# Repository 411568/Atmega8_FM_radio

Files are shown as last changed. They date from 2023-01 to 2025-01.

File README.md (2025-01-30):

<p align="center">Atmega8_FM_radio</p>

<h2>🧐 Features</h2>

This project is a revision of one of my old designs, created a long long time ago when atmel atmega chips where still dirty cheap.

It contains two seperate boards: 
 - main_radio_board - this one contains an Atmega8 microcontroller, TEA5767 FM radio module, PAM8302 amplifier module and power connector. 
 - display_and_controls_board - this one is specificly designed to fit in an old Unitra radio case, it has LEDs used as radio frequency indicators, rotary encoder for changing the frequency, potentiometer for volume and some additional buttons.

<h2>📱 Electronics design</h2>

My FM radio is based on the TEA7567 module, that is connected to an Atmega8A-PU microconotroller via I2C. Then it's output goes to the connector, then on the main panel passes through a logarithmic potentiometer for volume control 
and comes back to the PAM8302 D-class amplifier module. I chose it because it works well with my speaker, which is the one used in the original Unitra radio (it is probably over 40 years old and still works very well).

The schematic and PCB were both designed using KiCAD 6.0

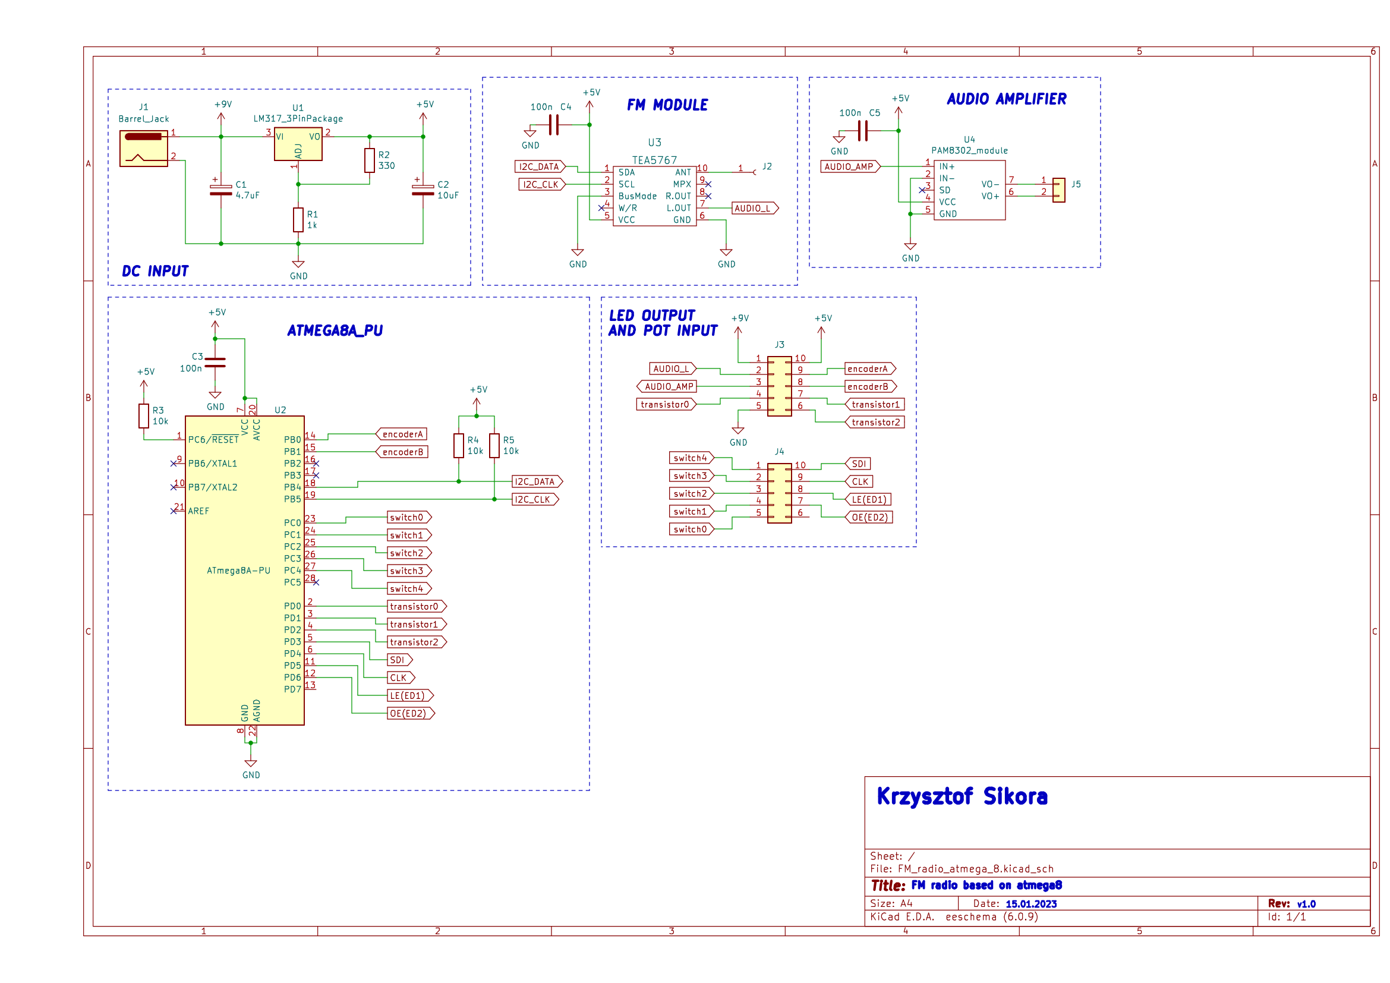
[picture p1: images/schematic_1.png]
schematic kicad


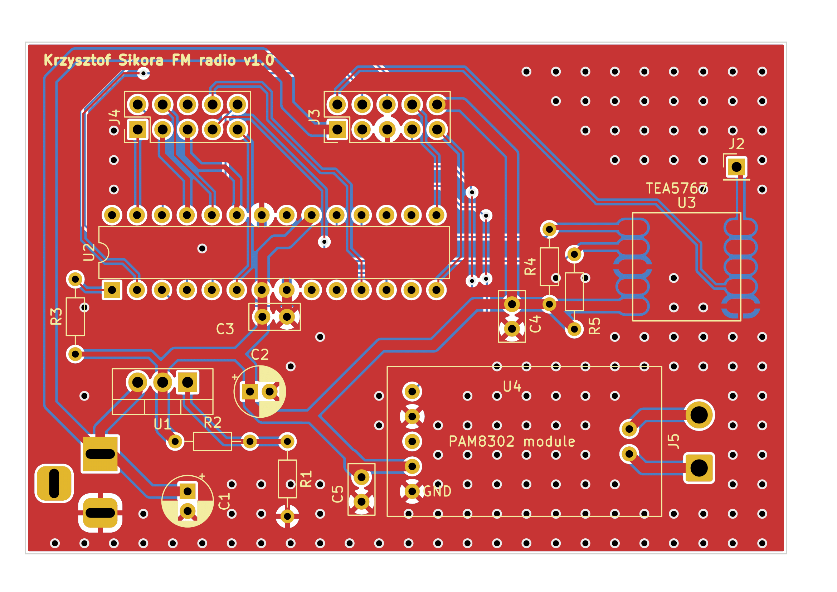
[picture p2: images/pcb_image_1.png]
PCB kicad


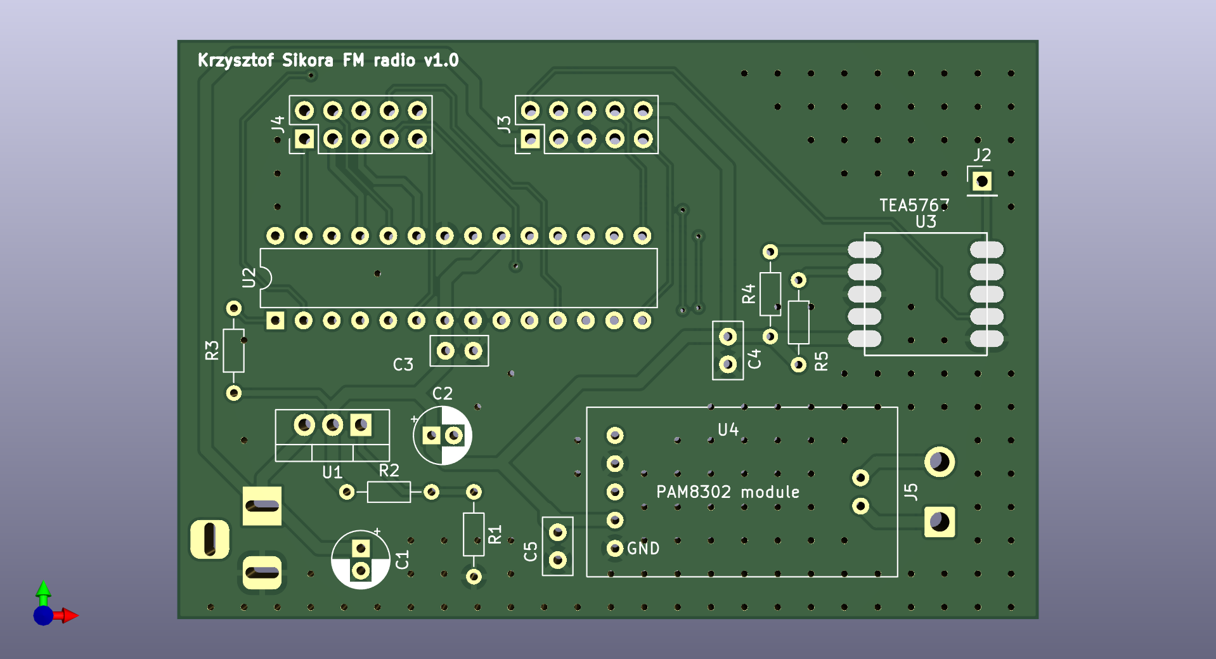
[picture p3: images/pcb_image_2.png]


<h2>💈 Connector pinouts</h2>

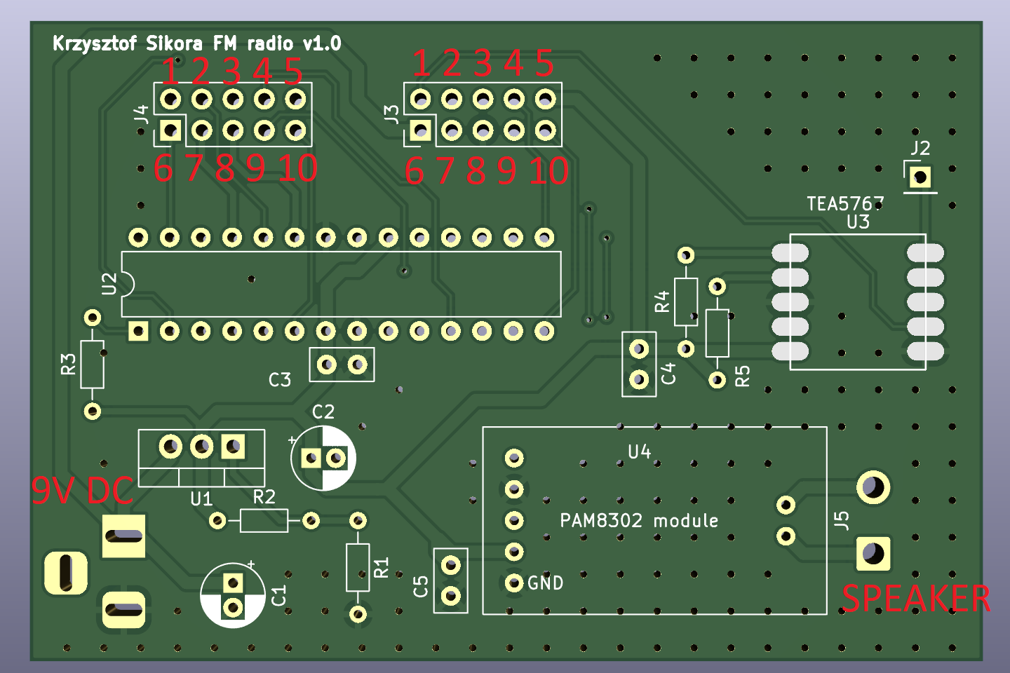
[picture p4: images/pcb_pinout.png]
pcb view with pinout


In the image above you can see the 9V DC input jack location, the speaker output connector and two pin headers (IDC connectors).

J4 connector pinout (all of these are generic GPIO pins of the Atmega8):
* 1  - switch 3
* 2  - switch 1
* 3  - NC
* 4  - LE(ED1)
* 5  - SDI
* 6  - switch 4
* 7  - switch 2
* 8  - switch 0
* 9  - OE(ED2)
* 10 - CLK

J3 connector pinout:
* 1  - TEA5767 output (to potentiometer)
* 2  - transistor 0
* 3  - transistor 2
* 4  - encoder B
* 5  - 5V DC
* 6  - 9V DC
* 7  - PAM8302 input (from potentiometer)
* 8  - GND
* 9  - transistor 1
* 10 - encoder A

<h2>📧 Atmega code</h2>

The code is split into several files, you can find them all on my github. 
* encoder.c - containing functions for interfacing with the rotary encoder
* i2c_lib.c - bit banging i2c library
* led_screen.c - functions for interfacing with led driver
* tea5767.c - functions for the TEA5767 FM radio module
* main.c - main program

Main function for the tea5767 is the send_freq function that tells the module to set a certain frequency:

```c
void send_freq()
{
	unsigned char frequencyH;
	unsigned char frequencyL;
	unsigned int frequencyB;

	frequencyB = 4 * (frequency * 1000000 + 225000) / 32768;
	frequencyH = frequencyB >> 8;
	frequencyL = frequencyB & 0xFF;

    //data transmition 
    I2C_Start();
	I2C_Write(TEA5767_ADDRESS_W);
	I2C_Write(frequencyH);
	I2C_Write(frequencyL);
	I2C_Write(0xB0);
	I2C_Write(0x10);
	I2C_Write(0x00);
    I2C_Stop();

    _delay_ms(10);
}
```

and the search function:

```c
void search(uint8_t direction)
{
	unsigned char frequencyH;
	unsigned char frequencyL;
	unsigned int frequencyB;
    double temp = 88.0;

    if(direction == 1)
    {
        temp = frequency + 0.1; 
    }
    else
    {
        temp = frequency - 0.1; 
    }

	frequencyB = 4 * (temp * 1000000 + 225000) / 32768;
	frequencyH = frequencyB >> 8;
	frequencyL = frequencyB & 0xFF;

    I2C_Start();
	I2C_Write(TEA5767_ADDRESS_W); //send address for writing
	I2C_Write(frequencyH |= 0b01000000); //search mode
	I2C_Write(frequencyL);
    if(direction == 1)
    {
        I2C_Write(0b11010000); //search up with mid adc 
    }
    else
    {
        I2C_Write(0b01010000); //search down with mid adc
    }
	I2C_Write(0x10);
	I2C_Write(0x00);

    I2C_Stop();

    _delay_ms(10);
}
```

You can find what the specific bytes being sent to the module mean in its datasheet.

In the main program loop we check the encoder status:

```c
if(val != val_tmp)
{
    if( (val == 3 && val_tmp == 1) || (val == 0 && val_tmp == 2) )
    {
        if(frequency < 108.0)
        {
            frequency += 1.0;
            send_freq(); 
            display(frequency); //display the current frequency
            search(1); //search up from the set freq
        }
    }
    else if( (val == 2 && val_tmp == 0) || (val == 1 && val_tmp == 3) )
    {
        if(frequency > 88.0)
        {
            frequency -= 1.0;
            send_freq();
            display(frequency); //display the current frequency
            search(0); //search down from the set freq
        }
    }
}
```
and change the frequency by 1Hz, then search up from that frequency to fine tune the radio automatically.

In addition to that there are also button inputs:

```c
if(bit_is_clear(button_1_port, button_1_pin)) 
{
    _delay_ms(15); //debounce
    if(bit_is_clear(button_1_port, button_1_pin))
    {
        search(1);
        _delay_ms(500);
        read_freq();
        display(frequency); //display the current frequency
    }
}
```

after pressing the button, the module starts an up search from the current frequency. 
Same aplies to the search down.
You can also change the frequency to one from the predefined tabel by pressing button number 4 or 5.

<h2>💻 Parts list</h2>

As it was just a revision of an older schematic, I did not bother to try and redesign it with newer uC etc. I just used the parts from the previous version (soldered onto a prototype board) or those I had lying around. 
Because of that the design may look a bit peculiar and I decided not to make a BOM file for it. Let me just list them in here for you:
* Atmega8A-PU microcontroller
* TEA5767 module
* PAM8302 amplifier module
* 2x IDC connector for the front panel
* LM317 for power step-down
* 9V DC jack input
* 3x ceramic 100nF capacitor
* 10uF and 4.7uF electrolytic capacitors
* 3x 10k resistor

<h2>📺 Front panel board</h2>

This board is used as my front panel for controls and displaying the current frequency etc.

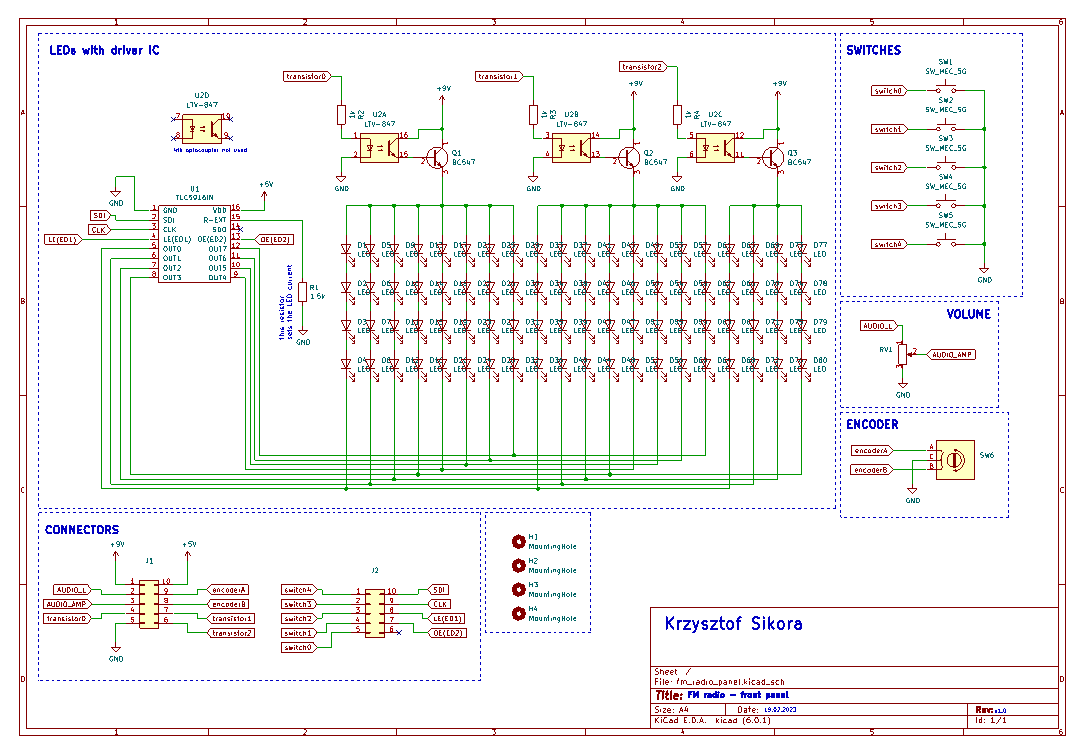
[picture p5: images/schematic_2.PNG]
schematic kicad


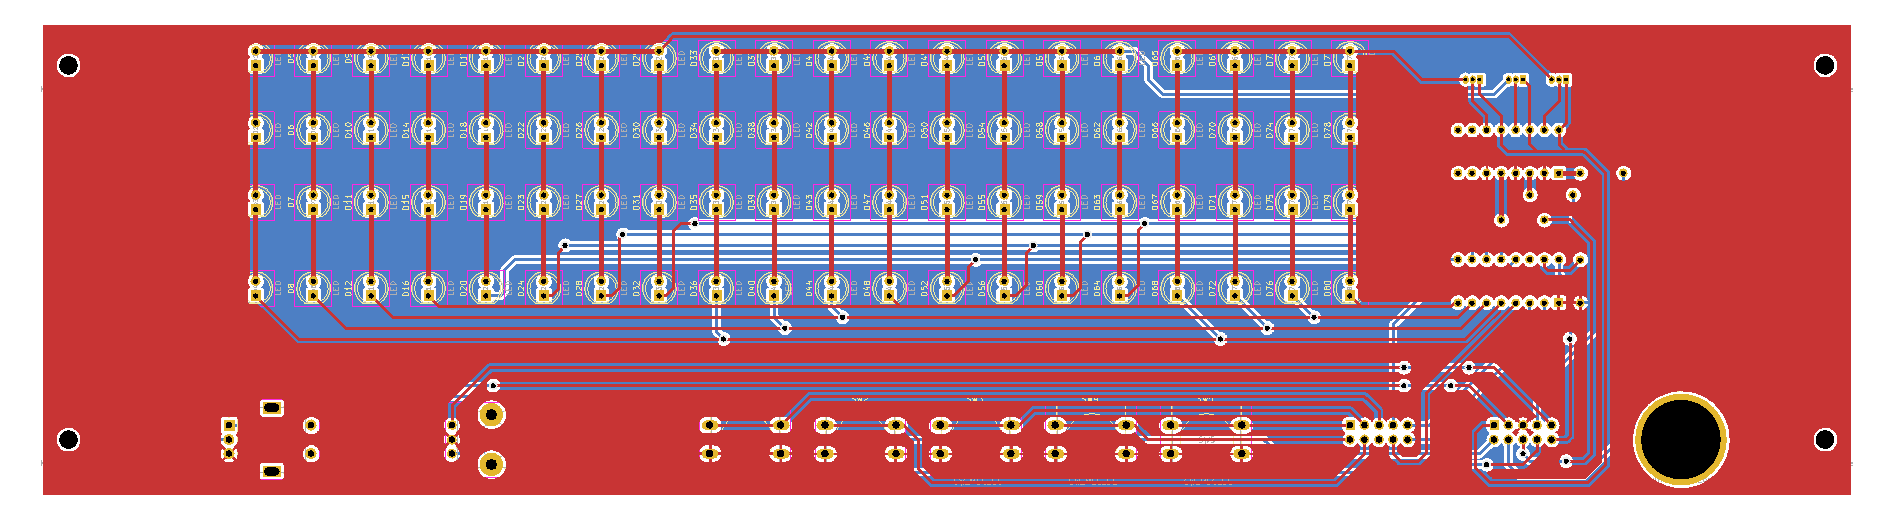
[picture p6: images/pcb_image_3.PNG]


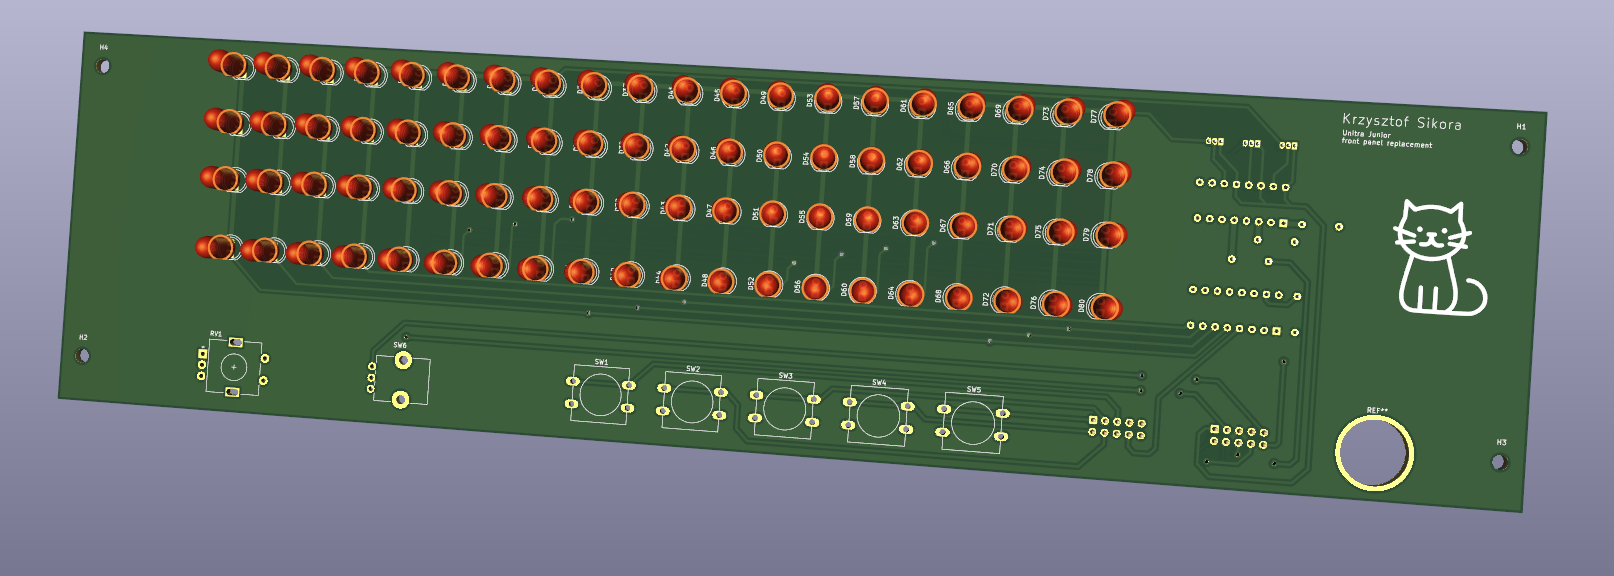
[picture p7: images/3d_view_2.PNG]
3d view


<h2>💻 Parts list</h2>

* LTV847 optocoupler
* TLC5916IN LED driver
* 3x 1kOhm resistor
* 1.5kOhm resistor
* 5x tact switch
* logarithmic potentiometer for audio control
* rotary encoder
* 2x IDC connector
* a lot of LEDs (red)

<h2>🛡️ License:</h2>

This project is licensed under the MIT License.

<h2> 🙋‍♂️Authors </h2>

- Krzysztof Sikora

<h2>💖Like my work?</h2>

If you have any questions about the project feel free to contact us via email: krzysieksikora717@gmail.com

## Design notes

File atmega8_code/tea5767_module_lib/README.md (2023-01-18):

# AVR_TEA5767
TEA5767 Library for AVR<br>
<br>
This is an AVR library for TEA5767. <br>
This library was only tested with ATmega128A so you may need to change UART & TWI codes<br>
if you're using diffent MCU from AVR family.
<br>
[Tutorial]<br>
https://blog.naver.com/eziya76/221278359585<br>
https://blog.naver.com/eziya76/221280558615<br>

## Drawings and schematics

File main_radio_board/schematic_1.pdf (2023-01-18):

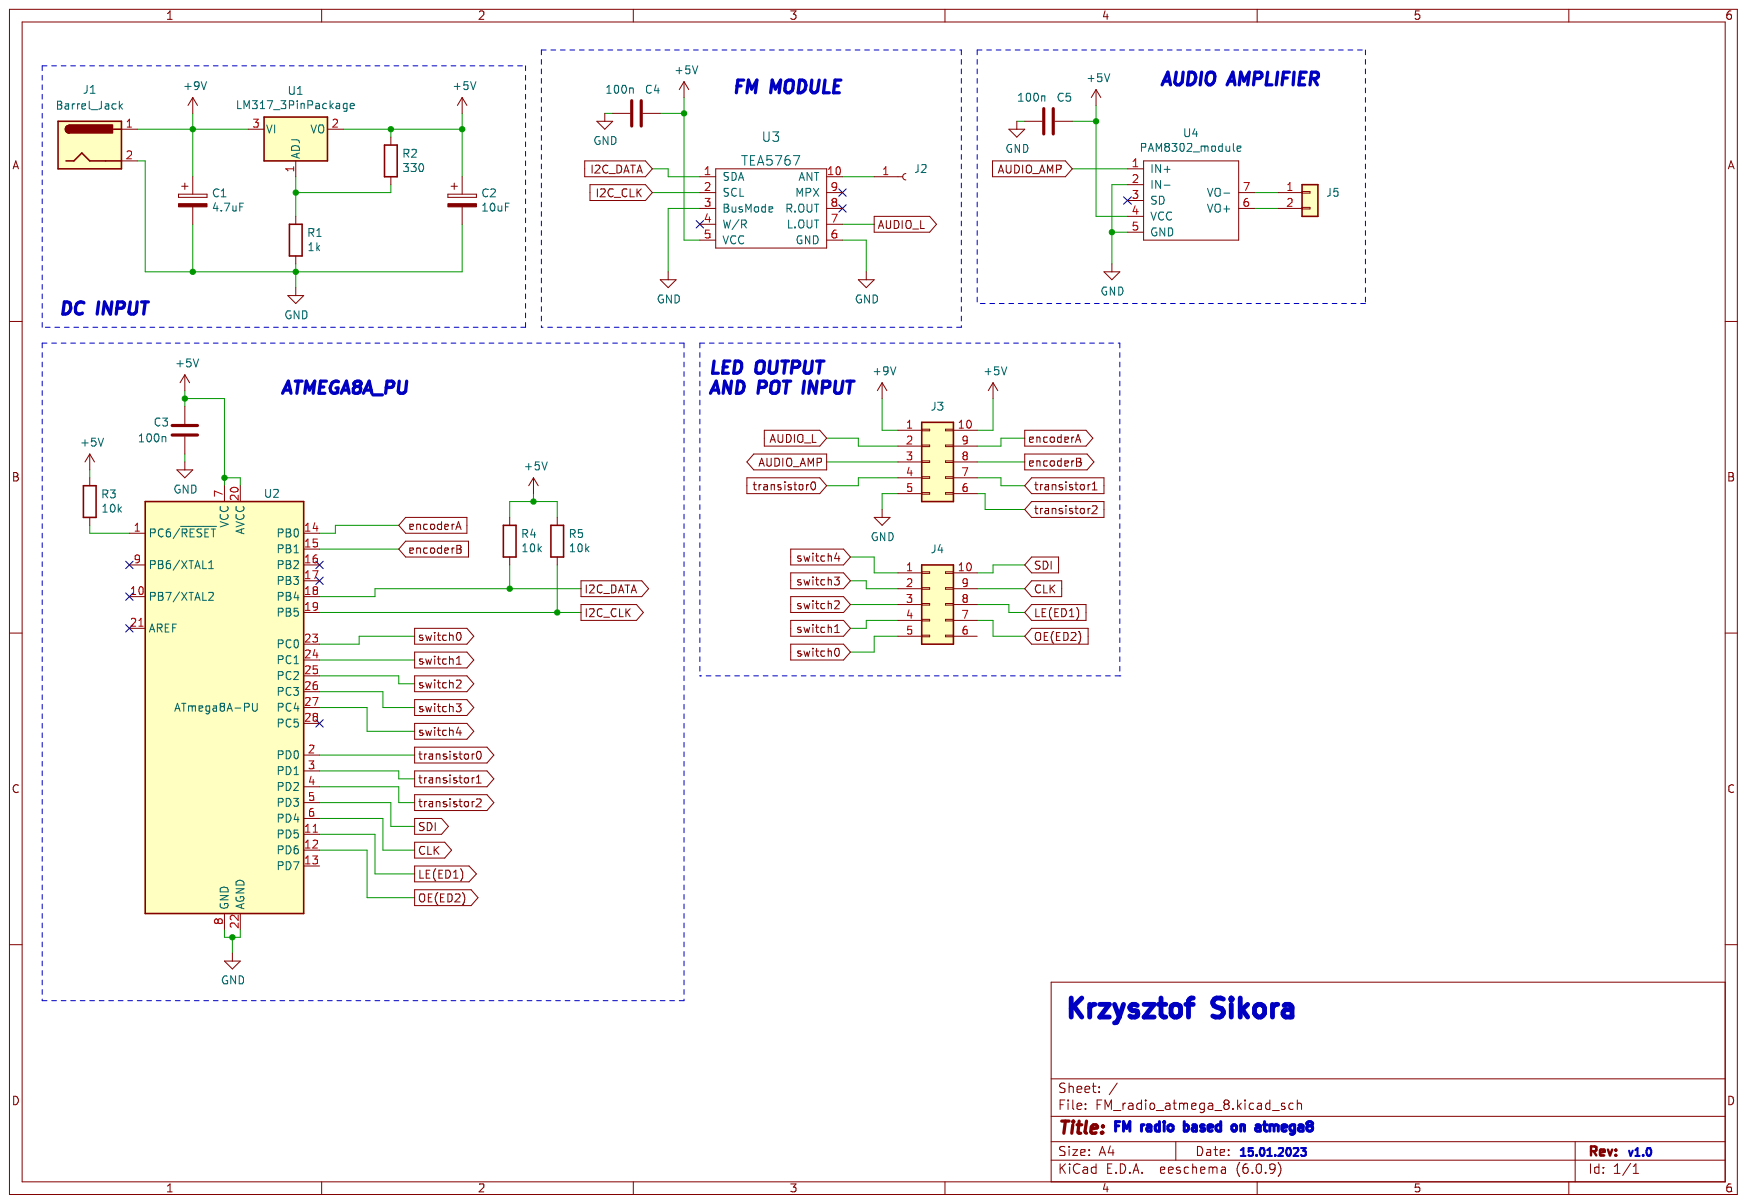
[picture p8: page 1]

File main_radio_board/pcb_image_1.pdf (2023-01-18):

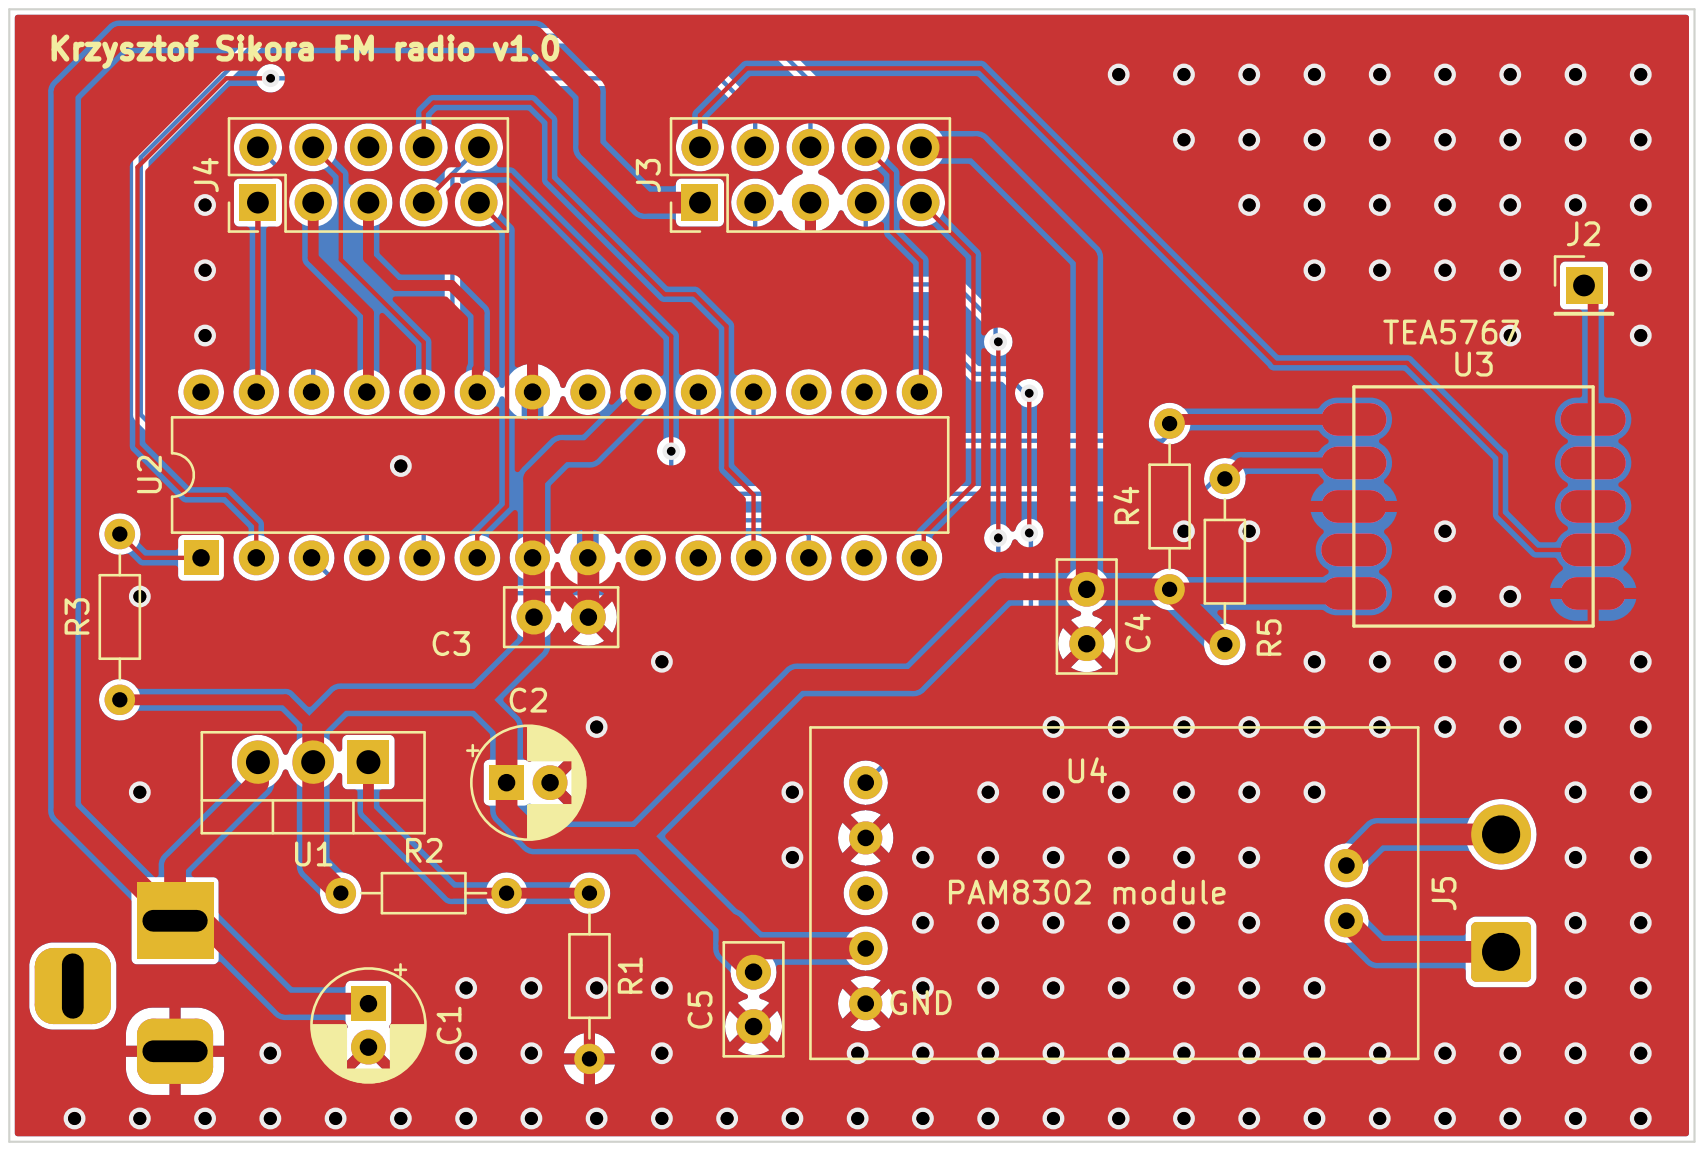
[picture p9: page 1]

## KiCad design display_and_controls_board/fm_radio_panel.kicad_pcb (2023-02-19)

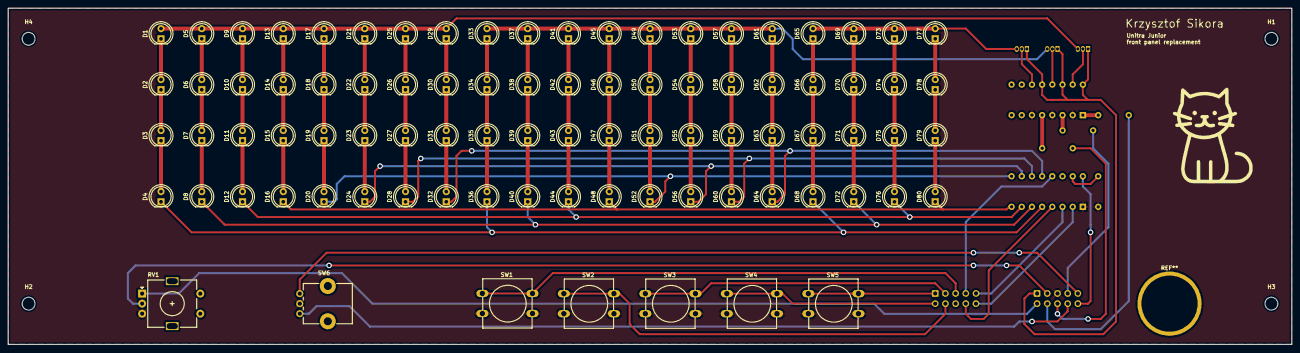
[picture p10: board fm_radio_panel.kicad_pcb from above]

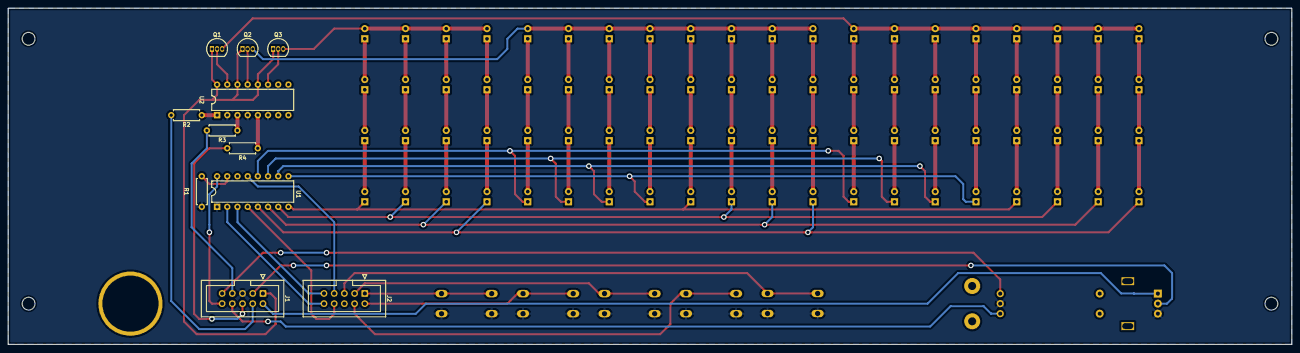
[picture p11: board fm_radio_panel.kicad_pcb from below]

Board: 2 copper layers, 320.0 x 83.8 mm, 102 parts (11 on the bottom side), 97 nets.

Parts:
D1, D2, D3, D4, D5, D6, D7, D8, D9, D10, D11, D12, D13, D14, D15, D16, D17, D18, D19, D20, D21, D22, D23, D24, D25, D26, D27, D28, D29, D30, D31, D32, D33, D34, D35, D36, D37, D38, D39, D40, D41, D42, D43, D44, D45, D46, D47, D48, D49, D50, D51, D52, D53, D54, D55, D56, D57, D58, D59, D60, D61, D62, D63, D64, D65, D66, D67, D68, D69, D70, D71, D72, D73, D74, D75, D76, D77, D78, D79, D80: LED; LED_D5.0mm
H1, H2, H3, H4: MountingHole; MountingHole_3.2mm_M3
J1, J2: Conn_02x05_Counter_Clockwise; IDC-Header_2x05_P2.54mm_Vertical
Q1, Q2, Q3: BC547; TO-92_Inline
R1: 1.5k; R_Axial_DIN0207_L6.3mm_D2.5mm_P7.62mm_Horizontal
R2, R3, R4: 1k; R_Axial_DIN0207_L6.3mm_D2.5mm_P7.62mm_Horizontal
RV1: R_Potentiometer; RotaryEncoder_Alps_EC11E-Switch_Vertical_H20mm
SW1, SW2, SW3, SW4, SW5: SW_MEC_5G; SW_PUSH-12mm
SW6: RotaryEncoder; Potentiometer_Alps_RK09K_Single_Vertical
U1: TLC5916IN; DIP-16_W7.62mm
U2: LTV-847; DIP-16_W7.62mm

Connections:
+5V: J1.10, U1.16 (VDD)
+9V: J1.1, Q1.1 (C), Q2.1 (C), Q3.1 (C), U2.12, U2.14, U2.16
AUDIO_AMP: J1.3, RV1.2
AUDIO_L: J1.2, RV1.1
CLK: J2.9, U1.3 (CLK)
GND: J1.5, R1.2, RV1.3, SW1.2, SW2.2, SW3.2, SW4.2, SW5.2, SW6.C, U1.1 (GND), U2.2, U2.4, U2.6
LE(ED1): J2.8, U1.4 (LE(ED1))
unnamed: D1.1 (K), D2.2 (A)
unnamed: D1.2 (A), D5.2 (A), D9.2 (A), D13.2 (A), D17.2 (A), D21.2 (A), D25.2 (A), D29.2 (A), Q1.3 (E)
unnamed: D2.1 (K), D3.2 (A)
unnamed: D3.1 (K), D4.2 (A)
unnamed: D5.1 (K), D6.2 (A)
unnamed: D6.1 (K), D7.2 (A)
unnamed: D7.1 (K), D8.2 (A)
unnamed: D10.1 (K), D11.2 (A)
unnamed: D9.1 (K), D10.2 (A)
unnamed: D11.1 (K), D12.2 (A)
unnamed: D12.1 (K), D44.1 (K), D76.1 (K), U1.7 (OUT2)
unnamed: D13.1 (K), D14.2 (A)
unnamed: D14.1 (K), D15.2 (A)
unnamed: D15.1 (K), D16.2 (A)
unnamed: D16.1 (K), D48.1 (K), D80.1 (K), U1.8 (OUT3)
unnamed: D17.1 (K), D18.2 (A)
unnamed: D18.1 (K), D19.2 (A)
unnamed: D19.1 (K), D20.2 (A)
unnamed: D20.1 (K), D52.1 (K), U1.9 (OUT4)
unnamed: D21.1 (K), D22.2 (A)
unnamed: D22.1 (K), D23.2 (A)
unnamed: D23.1 (K), D24.2 (A)
unnamed: D24.1 (K), D56.1 (K), U1.10 (OUT5)
unnamed: D25.1 (K), D26.2 (A)
unnamed: D26.1 (K), D27.2 (A)
unnamed: D27.1 (K), D28.2 (A)
unnamed: D28.1 (K), D60.1 (K), U1.11 (OUT6)
unnamed: D29.1 (K), D30.2 (A)
unnamed: D30.1 (K), D31.2 (A)
unnamed: D31.1 (K), D32.2 (A)
unnamed: D32.1 (K), D64.1 (K), U1.12 (OUT7)
unnamed: D33.1 (K), D34.2 (A)
unnamed: D33.2 (A), D37.2 (A), D41.2 (A), D45.2 (A), D49.2 (A), D53.2 (A), D57.2 (A), D61.2 (A), Q2.3 (E)
unnamed: D34.1 (K), D35.2 (A)
unnamed: D35.1 (K), D36.2 (A)
unnamed: D4.1 (K), D36.1 (K), D68.1 (K), U1.5 (OUT0)
unnamed: D37.1 (K), D38.2 (A)
unnamed: D38.1 (K), D39.2 (A)
unnamed: D39.1 (K), D40.2 (A)
unnamed: D8.1 (K), D40.1 (K), D72.1 (K), U1.6 (OUT1)
unnamed: D41.1 (K), D42.2 (A)
unnamed: D42.1 (K), D43.2 (A)
unnamed: D43.1 (K), D44.2 (A)
unnamed: D45.1 (K), D46.2 (A)
unnamed: D46.1 (K), D47.2 (A)
unnamed: D47.1 (K), D48.2 (A)
unnamed: D49.1 (K), D50.2 (A)
unnamed: D50.1 (K), D51.2 (A)
unnamed: D51.1 (K), D52.2 (A)
unnamed: D53.1 (K), D54.2 (A)
unnamed: D54.1 (K), D55.2 (A)
unnamed: D55.1 (K), D56.2 (A)
unnamed: D57.1 (K), D58.2 (A)
unnamed: D58.1 (K), D59.2 (A)
unnamed: D59.1 (K), D60.2 (A)
unnamed: D61.1 (K), D62.2 (A)
unnamed: D62.1 (K), D63.2 (A)
unnamed: D63.1 (K), D64.2 (A)
unnamed: D65.1 (K), D66.2 (A)
unnamed: D65.2 (A), D69.2 (A), D73.2 (A), D77.2 (A), Q3.3 (E)
unnamed: D66.1 (K), D67.2 (A)
unnamed: D67.1 (K), D68.2 (A)
unnamed: D69.1 (K), D70.2 (A)
unnamed: D70.1 (K), D71.2 (A)
unnamed: D71.1 (K), D72.2 (A)
unnamed: D73.1 (K), D74.2 (A)
unnamed: D74.1 (K), D75.2 (A)
unnamed: D75.1 (K), D76.2 (A)
unnamed: D77.1 (K), D78.2 (A)
unnamed: D78.1 (K), D79.2 (A)
unnamed: D79.1 (K), D80.2 (A)
unnamed: Q1.2 (B), U2.15
unnamed: Q2.2 (B), U2.13
unnamed: Q3.2 (B), U2.11
unnamed: R1.1, U1.15 (R-EXT)
unnamed: R2.1, U2.1
unnamed: R3.1, U2.3
unnamed: R4.1, U2.5
OE(ED2): J2.7, U1.13 (OE(ED2))
SDI: J2.10, U1.2 (SDI)
encoderA: J1.9, SW6.A
encoderB: J1.8, SW6.B
switch0: J2.5, SW1.1
switch1: J2.4, SW2.1
switch2: J2.3, SW3.1
switch3: J2.2, SW4.1
switch4: J2.1, SW5.1
transistor0: J1.4, R2.2
transistor1: J1.7, R3.2
transistor2: J1.6, R4.2

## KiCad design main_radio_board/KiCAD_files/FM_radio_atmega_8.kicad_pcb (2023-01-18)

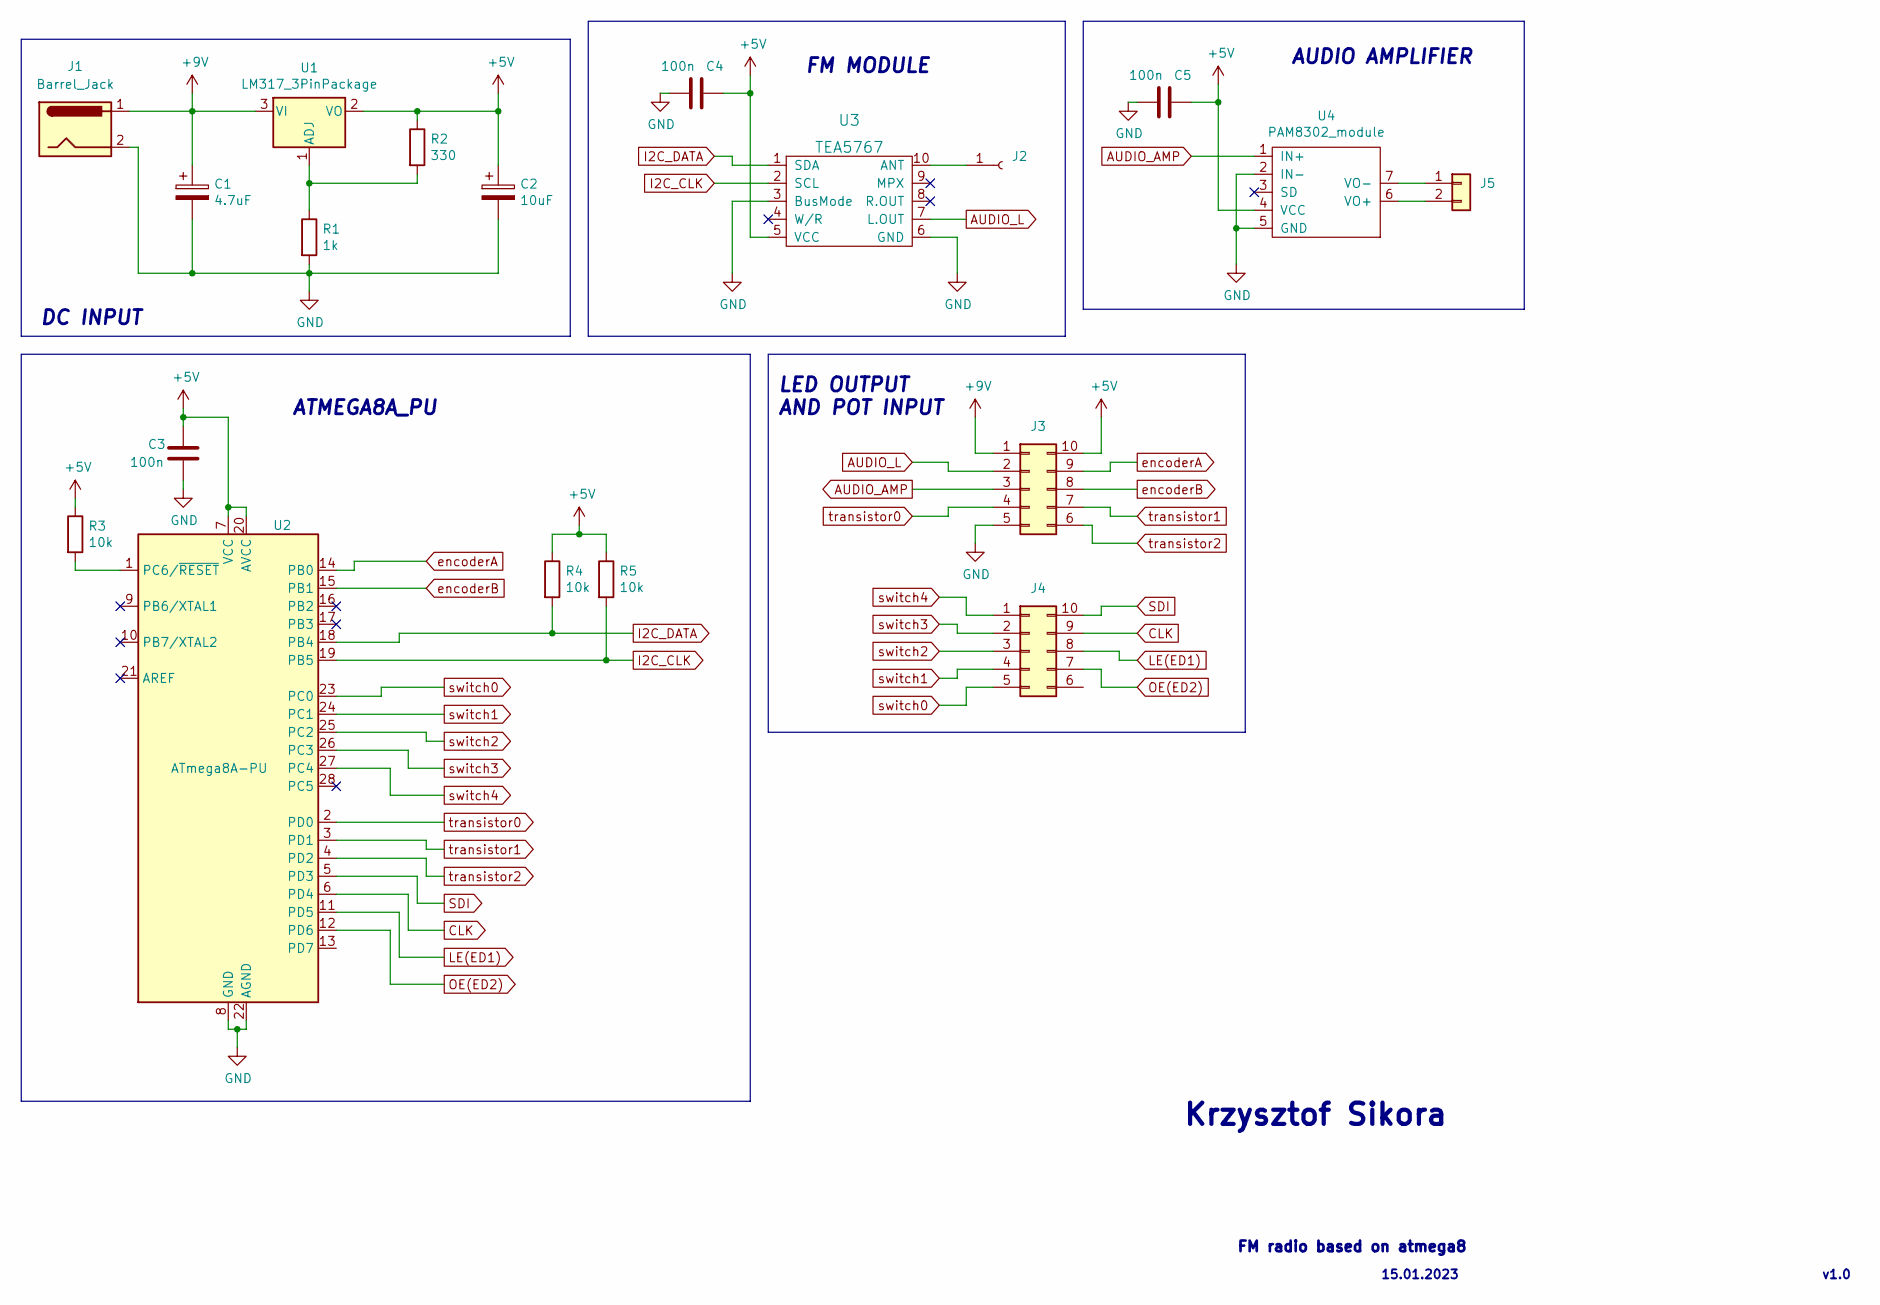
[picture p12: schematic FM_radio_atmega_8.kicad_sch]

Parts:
C1: 4.7uF; CP_Radial_D5.0mm_P2.00mm
C2: 10uF; CP_Radial_D5.0mm_P2.00mm
C3, C4, C5: 100n; C_Disc_D5.0mm_W2.5mm_P2.50mm
J1: Barrel_Jack; BarrelJack_Horizontal
J2: Conn_01x01_Female; PinHeader_1x01_P2.54mm_Vertical
J3, J4: Conn_02x05_Counter_Clockwise; PinHeader_2x05_P2.54mm_Vertical
J5: Conn_01x02; SolderWire-1sqmm_1x02_P5.4mm_D1.4mm_OD2.7mm
R1: 1k; R_Axial_DIN0204_L3.6mm_D1.6mm_P7.62mm_Horizontal
R2: 330; R_Axial_DIN0204_L3.6mm_D1.6mm_P7.62mm_Horizontal
R3, R4, R5: 10k; R_Axial_DIN0204_L3.6mm_D1.6mm_P7.62mm_Horizontal
U1: LM317_3PinPackage; TO-220-3_Vertical
U2: ATmega8A-PU; DIP-28_W7.62mm
U3: TEA5767; TEA5767_SMD
U4: PAM8302_module; PAM8302

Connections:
+5V: C2.1, C3.1, C4.1, C5.1, J3.10, R2.1, R3.1, R4.1, R5.1, U1.2 (VO), U2.7 (VCC), U2.20 (AVCC), U3.5 (VCC), U4.4 (VCC)
+9V: C1.1, J1.1, J3.1, U1.3 (VI)
AUDIO_AMP: J3.3, U4.1 (IN+)
AUDIO_L: J3.2, U3.7 (L.OUT)
CLK: J4.9, U2.6 (PD4)
GND: C1.2, C2.2, C3.2, C4.2, C5.2, J1.2, J3.5, R1.2, U2.8 (GND), U2.22 (AGND), U3.3 (BusMode), U3.6 (GND), U4.2 (IN-), U4.5 (GND)
I2C_CLK: R5.2, U2.19 (PB5), U3.2 (SCL)
I2C_DATA: R4.2, U2.18 (PB4), U3.1 (SDA)
LE(ED1): J4.8, U2.11 (PD5)
unnamed: J2.1, U3.10 (ANT)
unnamed: J5.1, U4.7 (VO-)
unnamed: J5.2, U4.6 (VO+)
unnamed: R1.1, R2.2, U1.1 (ADJ)
unnamed: R3.2, U2.1 (PC6/~RESET)
OE(ED2): J4.7, U2.12 (PD6)
SDI: J4.10, U2.5 (PD3)
encoderA: J3.9, U2.14 (PB0)
encoderB: J3.8, U2.15 (PB1)
switch0: J4.5, U2.23 (PC0)
switch1: J4.4, U2.24 (PC1)
switch2: J4.3, U2.25 (PC2)
switch3: J4.2, U2.26 (PC3)
switch4: J4.1, U2.27 (PC4)
transistor0: J3.4, U2.2 (PD0)
transistor1: J3.7, U2.3 (PD1)
transistor2: J3.6, U2.4 (PD2)

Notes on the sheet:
DC INPUT
v1.0
LED OUTPUT AND POT INPUT
Krzysztof Sikora
15.01.2023
AUDIO AMPLIFIER
ATMEGA8A_PU
FM MODULE
FM radio based on atmega8

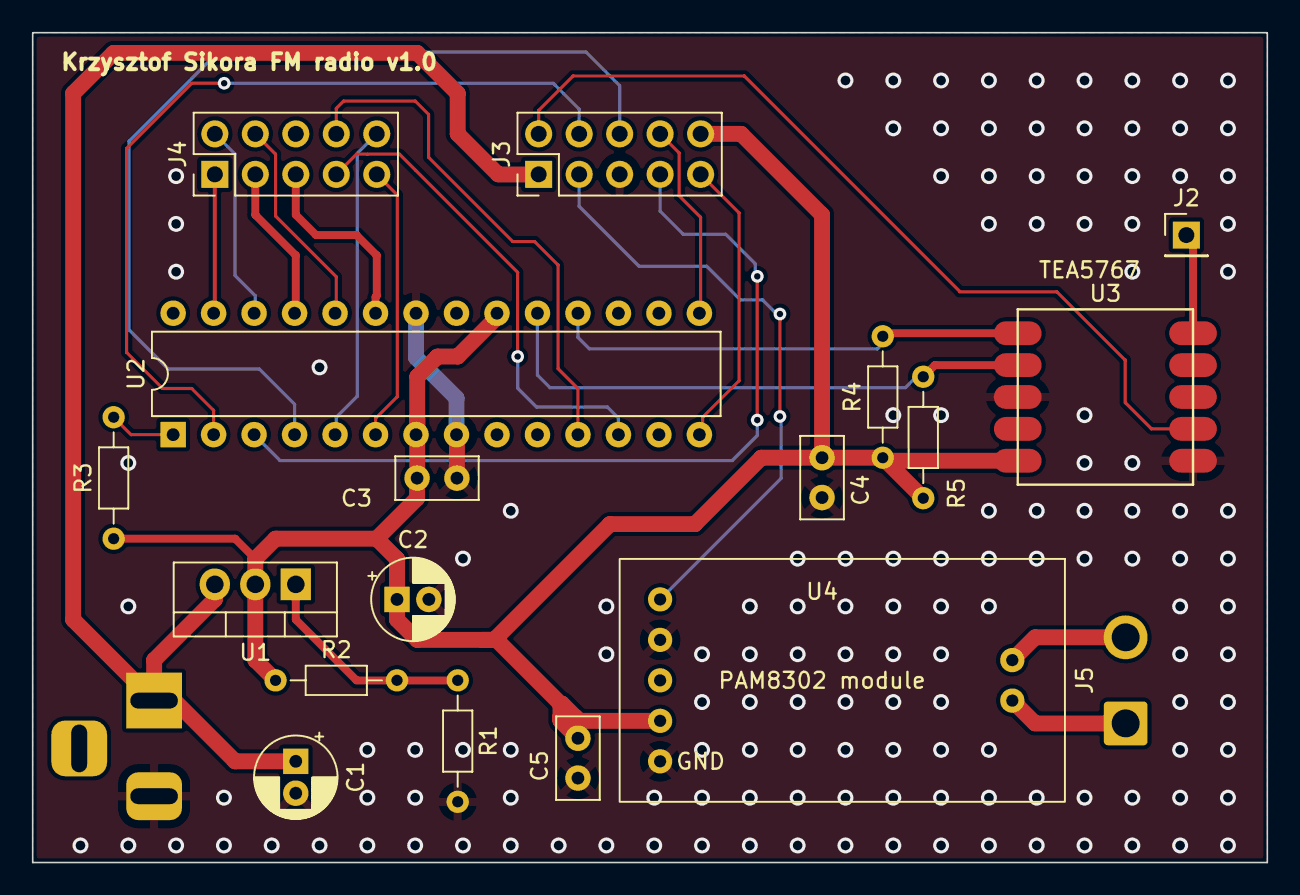
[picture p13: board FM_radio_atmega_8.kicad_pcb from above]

Board: 2 copper layers, 77.5 x 52.1 mm, 19 parts (1 on the bottom side), 26 nets.

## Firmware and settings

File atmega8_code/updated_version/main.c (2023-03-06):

//TODO
//Fix searching for stations
//find a better way to set frequency via rotary encoder

#ifndef F_CPU
#define F_CPU	8000000
#endif

#include <avr/io.h>
#include <util/delay.h>
#include <stdio.h>
#include <string.h>

//#include "tea5767.c"
#include "encoder.c"
#include "led_screen.c"


#define _BV(bit)			(1 << (bit))
#define bit_is_set(sfr, bit)		(_SFR_BYTE(sfr) & _BV(bit))
#define bit_is_clear(sfr, bit)		(!(_SFR_BYTE(sfr) & _BV(bit)))

#define button_1_pin PC0
#define button_1_port PINC

#define button_2_pin PC1
#define button_2_port PINC

#define button_3_pin PC2
#define button_3_port PINC

#define button_4_pin PC3
#define button_4_port PINC

#define button_5_pin PC4
#define button_5_port PINC


int main(void)
{
    //setup the I2C, start TEA5767 with frequency from the table
	setup();
                  
	//setup GPIO
    DDRC = 0x00; //C pins as inputs 
    DDRB = 0x00; //B pins as inputs 
    DDRD = 0xFF; //D pins as outputs
    PORTC = 0xFF; //C pins with internal pullup resistors
    PORTB = 0xFF; //C pins with internal pullup resistors
    

    //for rotary encoder
    uint8_t val_tmp = 0;
    uint8_t val = 0;
    val_tmp = read_encoder();

    //for station tab
    uint8_t station_number = 0;

    //enable led display
    display(frequency);

	//main loop
	while(1)
	{
		// ------ ENCODER ------ //
        val_tmp = read_encoder();

        if(val != val_tmp)
        {
            if( (val == 3 && val_tmp == 1) || (val == 0 && val_tmp == 2) )
            {
                if(frequency < 108.0)
                {
                    frequency += 1.0;
                    send_freq(); 
                    display(frequency); //display the current frequency
                    search(1); //search up from the set freq
                }
            }
            else if( (val == 2 && val_tmp == 0) || (val == 1 && val_tmp == 3) )
            {
                if(frequency > 88.0)
                {
                    frequency -= 1.0;
                    send_freq();
                    display(frequency); //display the current frequency
                    search(0); //search down from the set freq
                }
            }
        }

        val = val_tmp;


		// ------ SEARCH UP ------ //
		if(bit_is_clear(button_1_port, button_1_pin)) 
		{
			_delay_ms(15); //debounce
			if(bit_is_clear(button_1_port, button_1_pin))
			{
                search(1);
                _delay_ms(500);
                read_freq();
                display(frequency); //display the current frequency
			}
		}


		// ------ SEARCH DOWN ------ //
		if(bit_is_clear(button_2_port, button_2_pin)) 
		{
			_delay_ms(15); //debounce
			if(bit_is_clear(button_2_port, button_2_pin))
			{
                search(0);
                _delay_ms(500);
                read_freq();
                display(frequency); //display the current frequency
			}
		}


		// ------ ANIMATION ------ //
		if(bit_is_clear(button_3_port, button_3_pin)) 
		{
			_delay_ms(15); //debounce
			if(bit_is_clear(button_3_port, button_3_pin))
			{
                animate();
			}
		}


		// ------ TAB UP ------ //
		if(bit_is_clear(button_4_port, button_4_pin)) 
		{
			_delay_ms(15); //debounce
			if(bit_is_clear(button_4_port, button_4_pin))
			{
                if(station_number < 10)
                    station_number++;
                else
                    station_number = 0;
                frequency = frequencytab[station_number];
                display(frequency); //display the current frequency
                send_freq();
			}
		}


		// ------ TAB DOWN ------ //
		if(bit_is_clear(button_5_port, button_5_pin)) 
		{
			_delay_ms(15); //debounce
			if(bit_is_clear(button_5_port, button_5_pin))
			{
                if(station_number > 0)
                    station_number--;
                else
                    station_number = 10;
                frequency = frequencytab[station_number];
                display(frequency); //display the current frequency
                send_freq();
			}
		}
	}
}

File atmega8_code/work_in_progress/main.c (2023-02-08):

#include <avr/io.h>
#include <util/delay.h>
#include <avr/power.h>

//#include "pinDefines.h"
#include "i2c.h"

#define _BV(bit)			(1 << (bit))
#define bit_is_set(sfr, bit)		(_SFR_BYTE(sfr) & _BV(bit))
#define bit_is_clear(sfr, bit)		(!(_SFR_BYTE(sfr) & _BV(bit)))

#define TEA5767_ADDRESS_W               0b11000000	 //address for writing to the TEA5767 (0xC0)


//NOTE: those are old pin defines, have to change them later
#define TLC5916_CLK	            	PB3 			 //clk port for the led driver
#define TLC5916_SDI			PB2			             //data port 
#define TLC5916_LEED1			PB1 			     //port LE(ED1) 
#define TLC5916_OEED2			PB4			         //port OE(ED2) 

#define PC847_1				PC1			             //port pierwszego transoptora
#define PC847_2				PC2		             	 //port drugiego transoptora
#define PC847_3				PC3			             //port trzeciego transoptora

#define button_1			PD0			             //port przycisku frequency++
#define button_2			PD1			             //port przycisku frequency--

#define debounce_t 		 	20



//global variables
double frequency;
double frequencytab[] = {89.2, 91.5, 95.7, 96.4, 97.6, 99.7, 102.2, 104.5, 105, 106.7};
int station_number;



// send the frequency to the TEA module
void send_freq()
{
	unsigned char frequencyH;
	unsigned char frequencyL;
	unsigned int frequencyB;

	frequencyB = 4 * (frequency * 1000000 + 225000) / 32768;
	frequencyH = frequencyB >> 8;
	frequencyL = frequencyB & 0xFF;

    //data transmition 
	i2cStart();
	i2cSend(TEA5767_ADDRESS_W);
	i2cSend(frequencyH);
	i2cSend(frequencyL);
	i2cSend(0xB0);
	i2cSend(0x10);
	i2cSend(0x00);
	i2cStop();
}


void LED_loop(char setting)
{
	for(int i = 0; i < 8; i++)
	{
		if(setting & (1 << i)) //if the bit in "setting" is set to "1" then it sends a "1" to the serial port
		{
			PORTB = 0b00010100;
			_delay_ms(2);
			PORTB = 0b00011100;
			_delay_ms(2);

		}
		else
		{
			PORTB = 0b00010000;
			_delay_ms(2);
			PORTB = 0b00011000;
			_delay_ms(2);

		}
	}
}



//led set
void LED_send(char setting, int opto)
{
	PORTC = 2 << opto; //testing this option now

	if(opto == 0) //jeszcze nie wiem co ma tu byc
	{
		LED_loop(setting);
	}
	else if(opto == 1) //jesli jestem na srodku tam gdzie sa zamienione diody
	{
		char temporary = setting;
		setting = setting >> 2;

		if(temporary && 0x02 == 0x02)
		{
			setting = setting || 0x80;
		}
		if(temporary && 0x01 == 0x01)
		{
			setting = setting || 0x40;
		}

		LED_loop(setting);
	}
	else if(opto == 2) //tu jest chyba wszystko ok
	{
		LED_loop(setting);
	}


	_delay_ms(2);
	PORTB = 0b00010010;
	_delay_ms(2);
	PORTB = 0b00000000;
	_delay_ms(2);
}


//led animation
void animateLED()
{
	for(int i = 0; i < 8; i++)
	{
		LED_send(1 << i, 1); //te bity sa na odwrot na wyswietlaczu
		_delay_ms(10);
	}
	LED_send(0b10101010, 0); //od lewej bity sa od lewej na wyswietlaczu (chyba)
	_delay_ms(100);
	LED_send(0b01000001, 2); //tu sa 3 srodkowe bity ktores XDDD
	_delay_ms(100);
	LED_send(0b11000010, 1); //tutaj 7 i 8 sa na miejscu 1 i 2 a reszta jest przesunieta
}

void setup()
{
	initI2C();
	DDRB = 0xFF; //port B w trybie wyjścia
	DDRC = 0xFF; //port C w trybie wyjścia
	DDRD = 0x00; //port D ustawiony w tryb wejścia
	PORTD = 0x3; //ustawienie oporników podciągających (tylko piny PD0 i PD1)


    //for testing only
	animateLED();

    //starting frequency from the table
	frequency = frequencytab[0];
	station_number = 0;
	send_freq();
	_delay_ms(100);
}



// -------- MAIN -------- //
int main(void)
{
	setup();

	while(1)
	{
		// ------ Zwiększenie częstotliwości ------ //
		if(bit_is_clear(PIND, button_1))
		{
			_delay_ms(debounce_t);
			if(bit_is_clear(PIND, button_1))
			{
				if(station_number < 9)
					station_number++;
				else
					station_number = 0;

				frequency = frequencytab[station_number];
				send_freq();
			}
		}


		// ------ Zmniejszanie częstotliwości ------ //
		if(bit_is_clear(PIND, button_2))
		{
			_delay_ms(debounce_t);
			if(bit_is_clear(PIND, button_2))
			{
				if(station_number > 0)
					station_number--;
				else
					station_number = 9;

				frequency = frequencytab[station_number];
				send_freq();
			}
		}
	}

	return (0);
}
